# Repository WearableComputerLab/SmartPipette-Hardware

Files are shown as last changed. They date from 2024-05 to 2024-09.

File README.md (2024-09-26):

# SmartPipette-Hardware
This repository contains the files needed to 3D print the Smart Pipette. The schematic PDF details how to connect the electronic components on the hand controller and the digital tube rack.

The following list includes the necessary electronics and additional materials to build one Smart Pipette v1. 

## Electronics for Smart Pipette Hand Controller
- Adafruit QT-Py ESP32-C3
- Adafruit LiIon or LiPoly Charger BFF Add-On for QT Py
- Adafruit 1201 Vibrating Mini Motor Disc
- Sensata 9610R3.4KL2.0 Linear Potentiometer
- MPU6050 Motion Sensor module
- 3.7V, 800mA lithium battery
- Push Button Switch - 12mm Square
- P2N2222 NPN Transistor
- 10k Ohm 0.5 Resistor
- 1k Ohm 0.5 Resistor
- JST 2-pin cable
- JST Right-Angle Connector - Through-Hole 2-Pin
- Switch
- +Round Brass Tube: 5/16 inch (7.94 mm) diameter, 0.014-inch wall thickness, cut at 29 mm length.
- +Comp 3/8 inch x 3/4 inch Metal spring

## Electronics for Smart Pipette Digital Tube Rack
- Arduino Nano V3.0
- Push Button Switch - 12mm Square
- RP-C7.6-ST Force Sensitive Resistor (x4 units)
- 10k Ohm 0.5 Resistor (x5 units)
- +EVA mid-density Foam 6mm thick (Ethylene-vinyl acetate)

## Other Materials Needed
- Filament for 3D printer (90 or 100% density settings for strength)
- Light-duty wire, solder wire, and shrink wrap

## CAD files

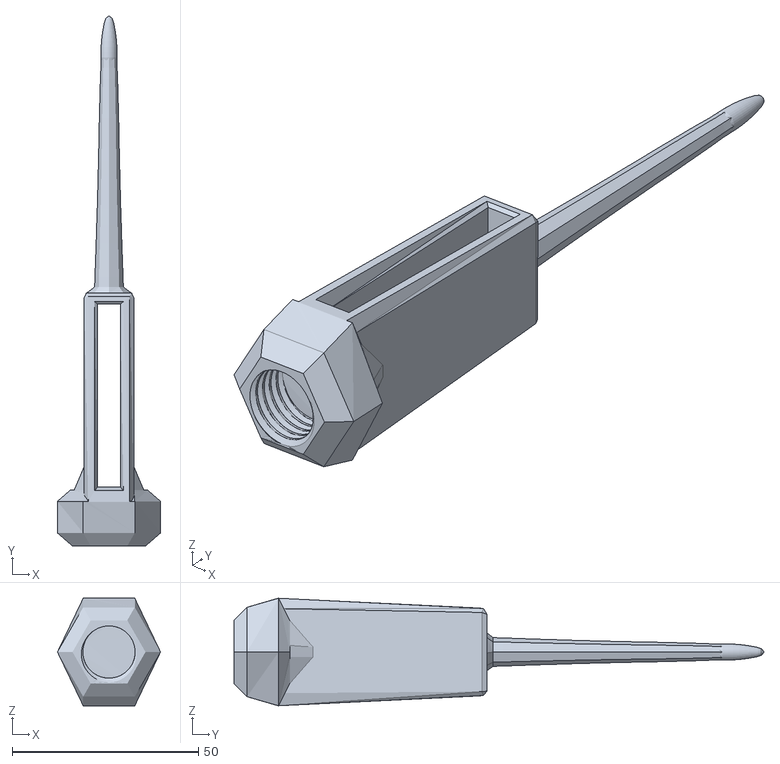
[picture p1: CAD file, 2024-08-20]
3D-Printable-Models/SP-Battery-850mAh.stl
27.7 x 142.4 x 28.9

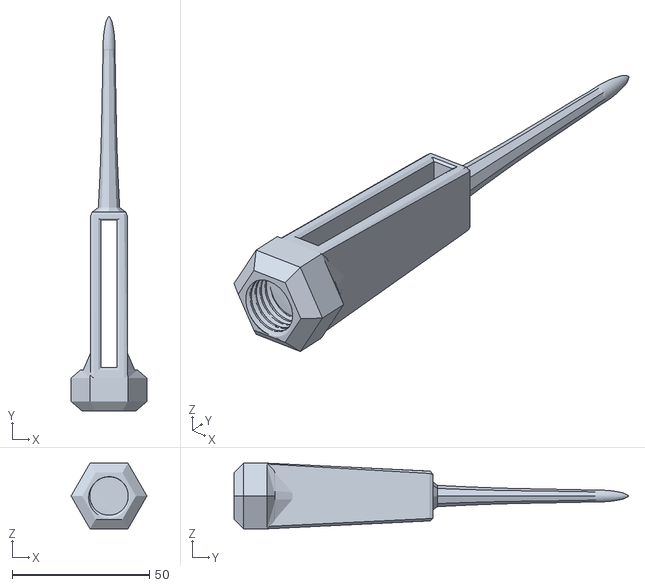
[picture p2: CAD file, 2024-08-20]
3D-Printable-Models/SP-Battery-1100mAh.stl
27.7 x 144.2 x 24.0

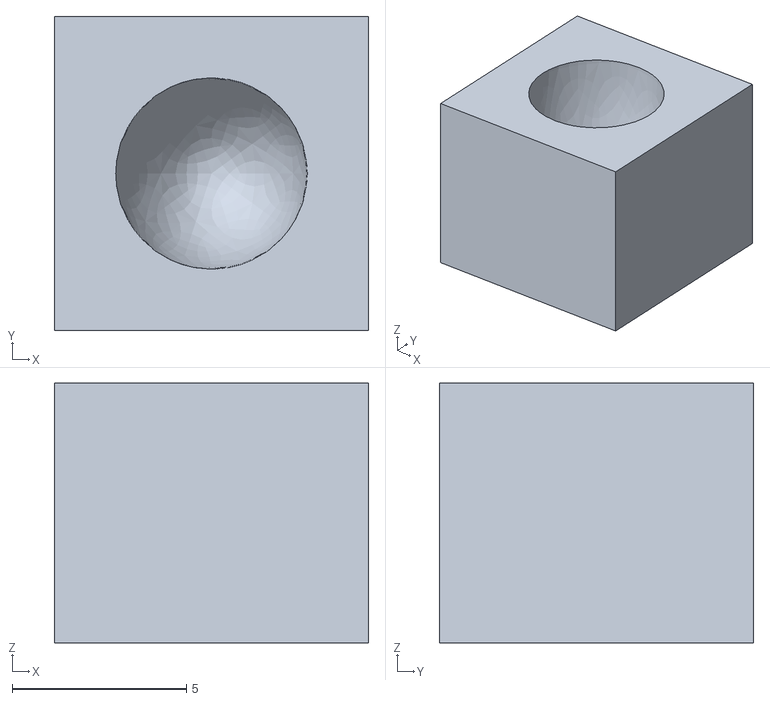
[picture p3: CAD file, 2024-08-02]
3D-Printable-Models/SP-Sample-Tubes-Green-Button.stl
9.00 x 9.00 x 7.45

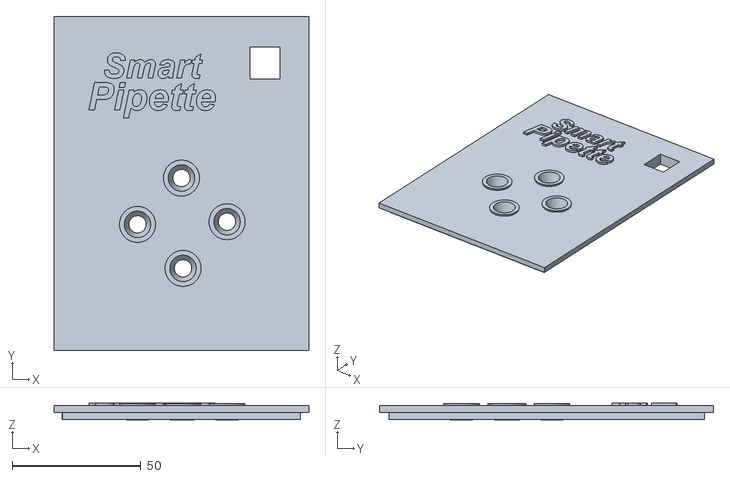
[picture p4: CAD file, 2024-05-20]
3D-Printable-Models/SP-Sample-Tubes-Lid.stl
99.0 x 129.8 x 6.43

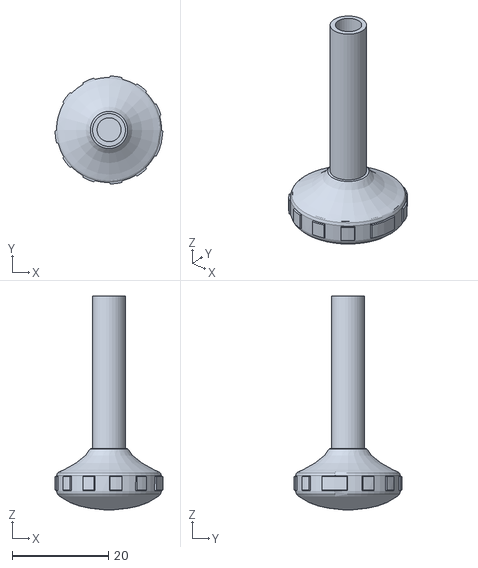
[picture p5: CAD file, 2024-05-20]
3D-Printable-Models/SP-Plunger.stl
22.5 x 22.5 x 44.6

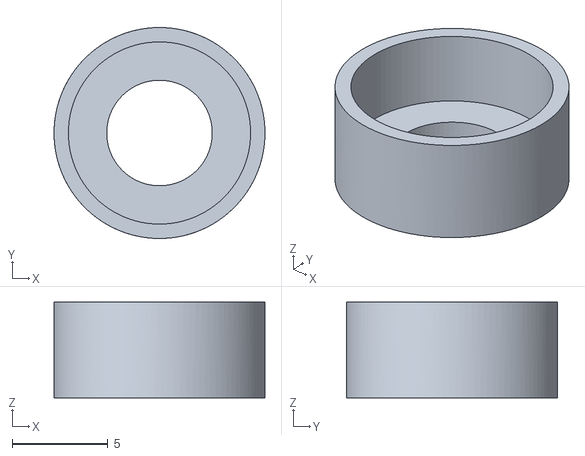
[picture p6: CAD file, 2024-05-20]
3D-Printable-Models/SP-Small-Ring.stl
11.0 x 11.0 x 5.00

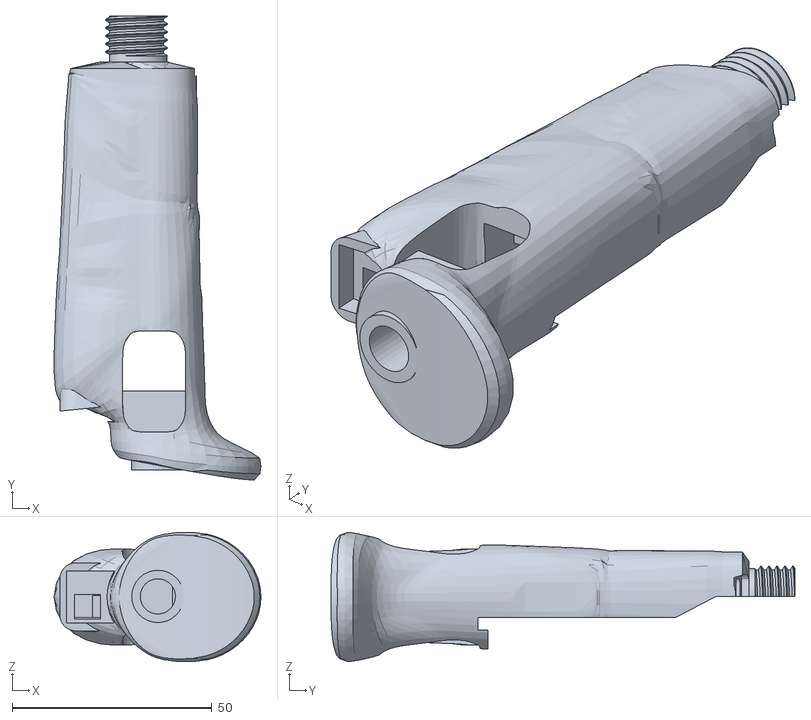
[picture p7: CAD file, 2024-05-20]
3D-Printable-Models/SP-Body-Top-1.stl
51.7 x 116.0 x 32.4

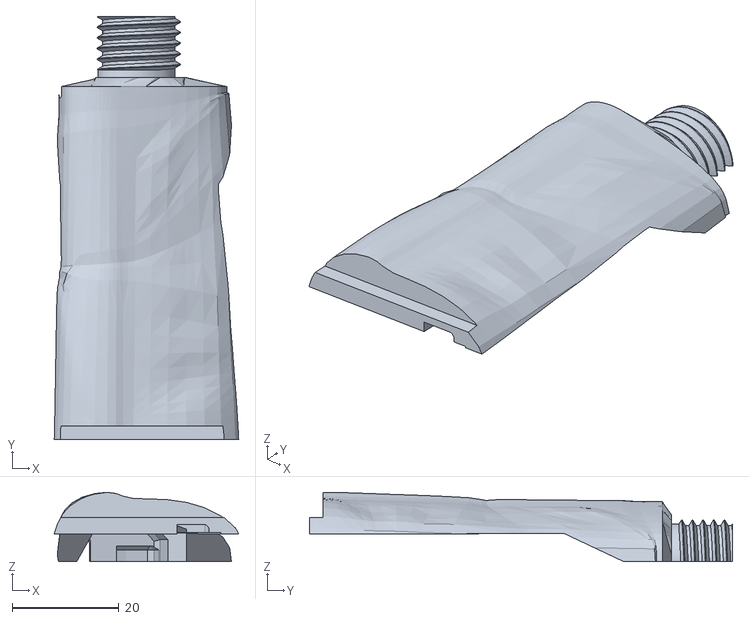
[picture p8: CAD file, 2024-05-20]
3D-Printable-Models/SP-Body-Top-2.stl
34.6 x 79.3 x 13.0

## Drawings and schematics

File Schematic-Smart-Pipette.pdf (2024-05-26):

# Smart

# Pipette

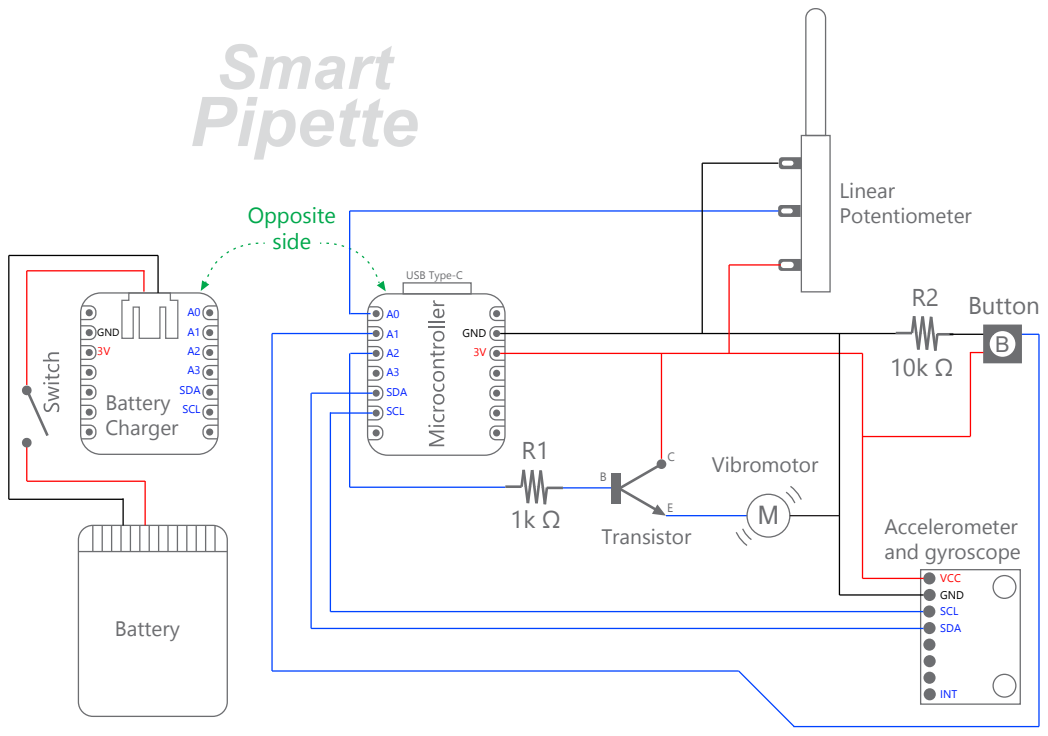
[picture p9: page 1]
Opposite side; A0 A1 A2 A3 SDA SCL; GND 3V; USB Type-C; VCC GND SCL SDA; INT; Linear Potentiometer; Vibromotor; Accelerometer; Button; Battery; Battery Charger

and gyroscope Transistor

# Smart

# Pipette

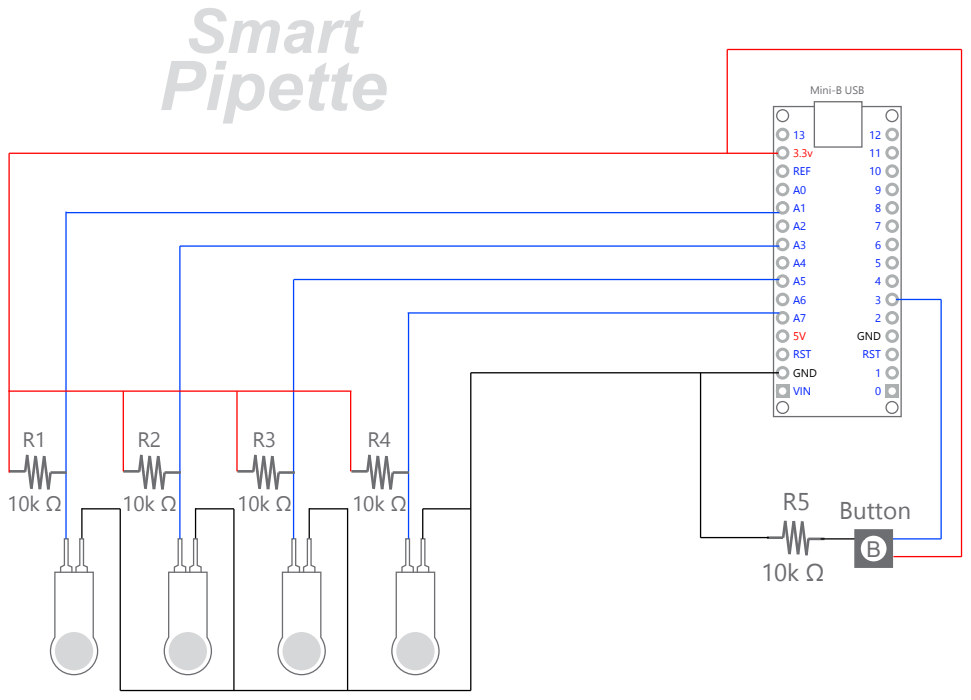
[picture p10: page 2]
13 3.3v REF A0 A1 A2 A3 A4 A5 A6 A7 5V RST GND VIN; Mini-B USB; GND RST10; R5 Button B

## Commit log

2024-05-20 uploading 3D assets
    [SP-Body-Bottom.stl, SP-Body-Top-1.stl, SP-Body-Top-2.stl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]
2024-05-26 Added the digital tube rack schematic
2024-07-15 Included the green button attachment
    [SP-Sample-Tubes-Green-Button.stl]
2024-08-02 Add files via upload
    Fixed the green button (was 10x smaller)
    [SP-Sample-Tubes-Green-Button.stl]
2024-08-20 Updated battery holder and provide two options
    SP-Battery-850mAh.stl is designed for a 3.7V battery with 850mAh
    SP-Battery-1100mAh.stl is designed for a 3.7V battery with 1100mAh
    [SP-Battery-1100mAh.stl, SP-Battery-850mAh.stl]
2024-09-26 Update README.md
    Adjusted the brass tubing specifications, which were imprecise.
